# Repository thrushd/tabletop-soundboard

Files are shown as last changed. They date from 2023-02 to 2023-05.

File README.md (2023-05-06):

# Tabletop Soundboard
## In progress!
A simple, compact, easy to use device to add music, ambiance, and sound effects to any tabletop RPG.

## How To
All data is given to the device through a micro SD card. Audio files, the config, and gif are all placed in the root directory with no sub folders.

### Listening
There are two audio outputs on the device, USB audio and a standard 3.5mm jack. For the USB audio, you can easily loop it back to play through your computer speakers, a connected bluetooth speaker, etc. Instructions for setting up this loopback can be found [here](https://www.addictivetips.com/windows-tips/output-mic-sound-to-speakers-windows-10/) for windows. 

### Scenes and Settings
Sounds are organized into 'scenes', with each scene containing up to 8 tracks (sound files). This organization is set with a configuration file, written in [TOML](https://toml.io/en/). There are three main settings, which can be set at three different levels: global, scene, and track level. Priority for settings is always given to lower levels, so a track level setting will always override a scene level setting, etc. If a setting is not given to a scene or track it will use the next highest defined setting.

| Setting | Description |
| --- | --- |
| `gain` | The volume level, decimal values from `0-1` |
| `loop` | Whether a track should start playing again when it reaches the end, `true` or `false` |
| `play` | Whether a track should start playing immediately when a scene is activated, `true` or `false` |
| `name` | Override the name of the scene or track filename, used in scene and track definitions |
| `filename` | Filename of sound, used in track definitions, include the extension |
| `tracks` | A list of filenames used to create a scene with minimal input, same conventions as `filename` |

A scene is defined by making a name after the keyword `scenes`, enclosed in brackets. So to make a new scene called `tavern` you would write: `[scenes.tavern]`. Under this definition you can add your scene level settings. After that you can define tracks. This follows the same convention, just the scene name followed by a number representing which track it should be. So to define track 3 in scene `tavern` you would write: `[tavern.3]`. Same as the scene level definitions, under this you put all of your track level settings.

### Fixed Tracks
Sometimes you might have a sound that is used in every scene. So instead of copy-pasting the definition of the track into each scene, you can define it as a special `fixed` track with the notation `[fixed.N]`, with `N` being the track number. This does however mean you cannot have a scene named `fixed`.

### Startup Animation
Gifs are fun, so when the device is powered on it will play a gif on the main display if one is present on the SD card. This name can be changed in the config file under the table `[gifs]` with the setting `startup`. If this behaviour is not desired it can be left out of the config and the device will boot without it.

### Config Example
```TOML
# Default Settings, required
[default]
gain = 0.5
loop = false
play = false

# Startup animation filename
[gifs]
startup = "startup.gif"

# Create fixed tracks that don't change depending on which scene you are in
# If track.n is declared in a scene it is ignored and overriden with the below items
[fixed.7]
filename = "dj_airhorn.wav"
name = "Nat 20"
gain = 1.0
[fixed.8]
filename = "sad_trombone.wav"
name = "Nat 1"
gain = 1.0

# Create a scene
[scenes.tavern]
name = "Old Ivey Tavern"  # rename the scene if desired, otherwise it will show as 'tavern'
[tavern.1]  # add a track
filename = "tavern_sounds_1.wav"  # specify the filename
name = "Tavern Sounds"  # change the displayed name if you want
play = true  # set if it should play on scene start
loop = true  # set if the track should loop or not
gain = 0.3  # set a non default volume gain
[tavern.2]  # add another track
filename = "piano_3.wav"
name = "Piano"
play = true
gain = 0.75
[tavern.3]  # this track is fine with all of the default settings, no need to override
filename = "bang.wav"

[scenes.camp]
gain = 1.0
[camp.1]
filename = "wolf_howl.wav"
[camp.2]
filename = "wind.wav"
gain = 0.2
loop = true
play = true
[camp.3]
filename = "crackling_campfire.wav"
gain = 0.75
loop = true
play = true

# If defalt settings are fine it can get very minimal, just a list of the file names
[scenes.mountain]
loop = true
tracks = ["mountain_ambiance.wav", "avalanch.wav", "yetti_growl.wav"]
```

## Audio Files
### Format
The audio is handled by the teensy audio library, which only supports a certain format (16 bit PCM, 44100 Hz WAV files). Since most online resources provide all kinds of formats a simple tool is provided to convert these to the proper WAV format. It can be found under `/audio-convert`.

### Editing
[Audacity](https://www.audacityteam.org/) is a great free, open source, cross platform audio editor. It can be used to trim tracks you find online, add fade in/out, and other effects. 

[Getting started](https://manual.audacityteam.org/quick_help.html)

### Sources
- [Tabletop Audio](https://tabletopaudio.com/) - Good for longer, ambient tracks
- [Battlebards](https://battlebards.com/#/tracks) - Tons of variety, music, soundscapes, effects, voiceovers, but it is paid
- [Ambient Mixer RPG Category](https://rpg.ambient-mixer.com/) - Ambiance, user curated collections of tracks, no easy download, but there are sources given for most tracks
- [Freesound](https://freesound.org/) - Free, huge variety, need an account to download
- [SoundBible](https://soundbible.com/) - Free, decent collection, WAV format (need to right click and `save link as...` to actually download)
- [mixkit](https://mixkit.co/free-sound-effects/) - Free, decent collection, WAV format
- [pixabay](https://pixabay.com/sound-effects/) - Free, music and sound effects

## Feature Wishlist
- Scrolling text for longer file and scene names

## History
| Date | Firmware | PCBA | Case | 
| ---- | --- | ---- | ---- |
| 2022-02-19 | MVP working on breadboard | | |
| 2022-03-29 |  | First prototypes ordered | First prototypes ordered |
| 2023-04-22 | Ported to PCBA | Assembled and working | |

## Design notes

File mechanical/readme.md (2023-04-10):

Instructions on how to assemble the PCBA in the case. Tips for printing, sourcing, etc.

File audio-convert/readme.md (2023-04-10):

# Audio Conversion
Since the teensy requires a specific audio format (16 bit PCM, 44100 Hz WAV files), this simple GUI tool is provided as a convienience feature for batch converting audio files to the required format through FFMPEG.

## Instructions
1. Download, install, and verify FFPEG can be run from command line
2. Download and install python
3. Stage all files for conversion in a single folder
4. Double click the python script to run the GUI
5. Browse to the input directory, then browse to the directory you want the converted files to be in (this can be the same)
6. Convert!

If you just want to run the FFMPEG command without the GUI it's:
```
ffmpeg -i "example.mp3" -ar 44100 "example.wav"
```

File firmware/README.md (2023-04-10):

How to build PlatformIO based project (to be replaced)
=====================================

1. [Install PlatformIO Core](https://docs.platformio.org/page/core.html)
2. Download [development platform with examples](https://github.com/platformio/platform-teensy/archive/develop.zip)
3. Extract ZIP archive
4. Run these commands:

```shell
# Change directory to example
$ cd platform-teensy/examples/arduino-blink

# Build project
$ pio run

# Upload firmware
$ pio run --target upload

# Build specific environment
$ pio run -e teensy31

# Upload firmware for the specific environment
$ pio run -e teensy31 --target upload

# Clean build files
$ pio run --target clean
```

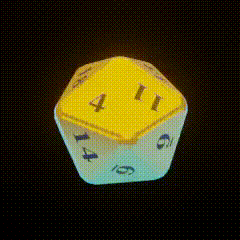
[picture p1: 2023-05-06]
sd/startup.gif

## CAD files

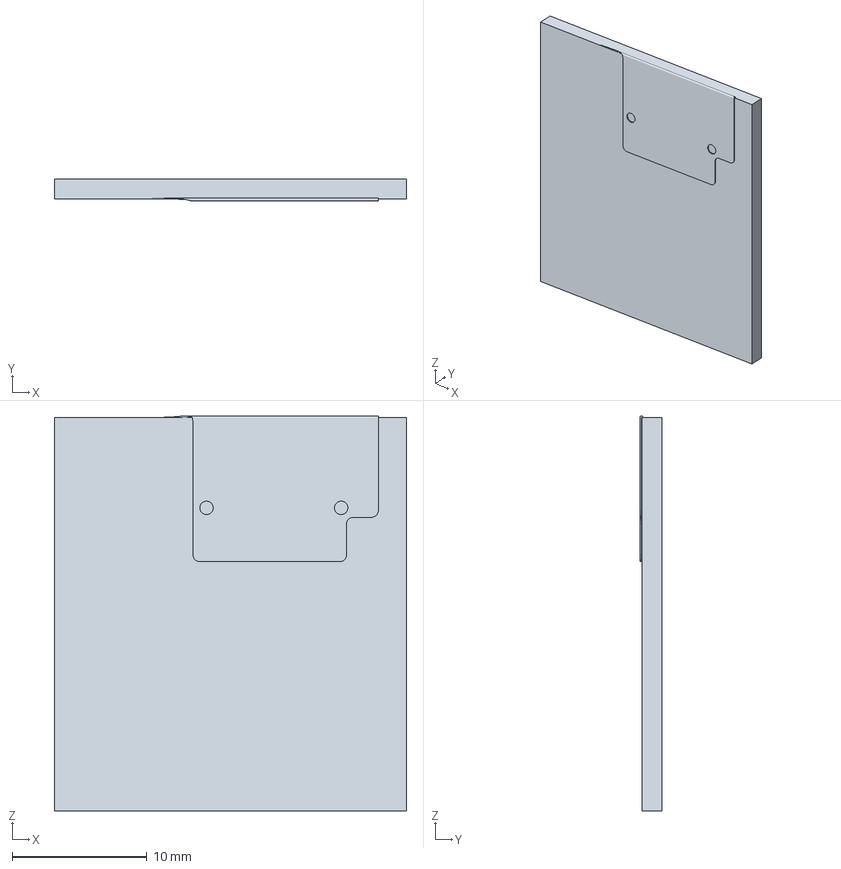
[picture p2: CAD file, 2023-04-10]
electrical/3d_models/ER-TFT013-2_tight.stp
26.2 x 1.64 x 29.3 mm

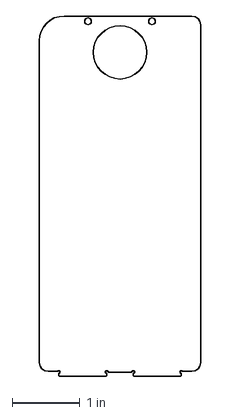
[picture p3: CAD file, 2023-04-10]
mechanical/plate.dxf
2.38 x 5.32 in

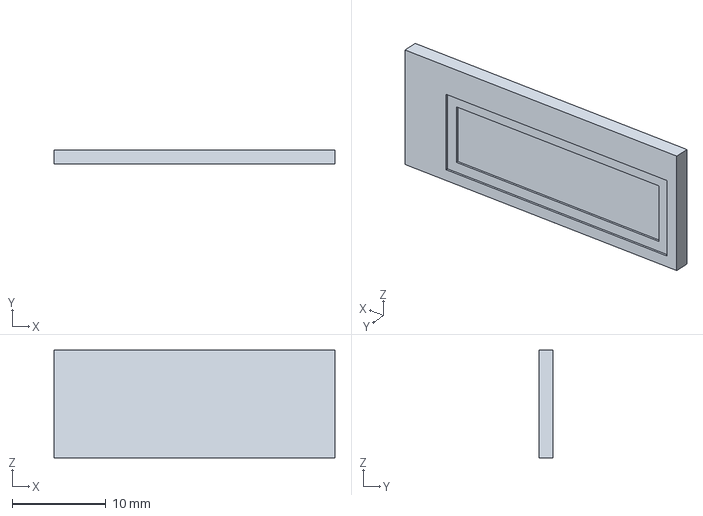
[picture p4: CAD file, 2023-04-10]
electrical/3d_models/ER-OLED0.91-1.stp
30.0 x 1.45 x 11.5 mm

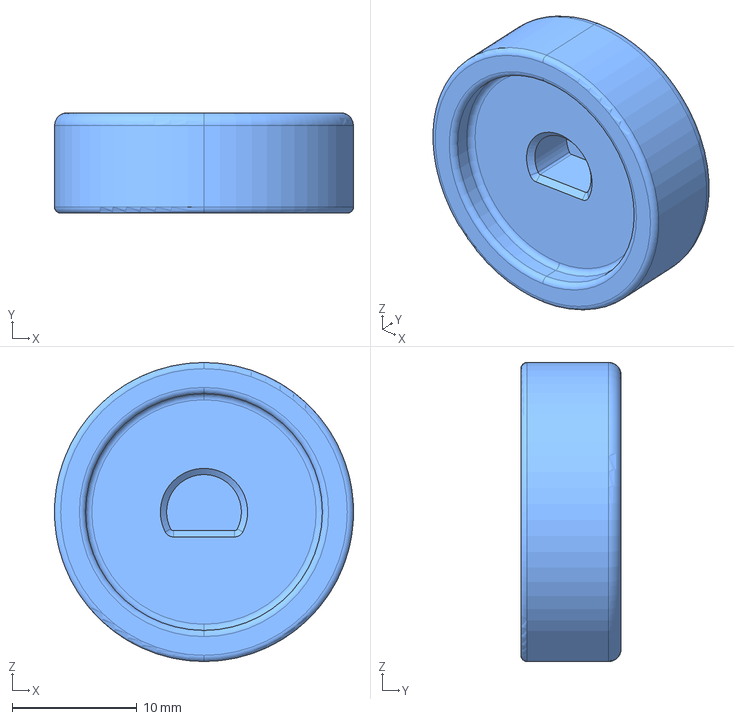
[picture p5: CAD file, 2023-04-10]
mechanical/knob.stp
24.0 x 8.05 x 24.0 mm

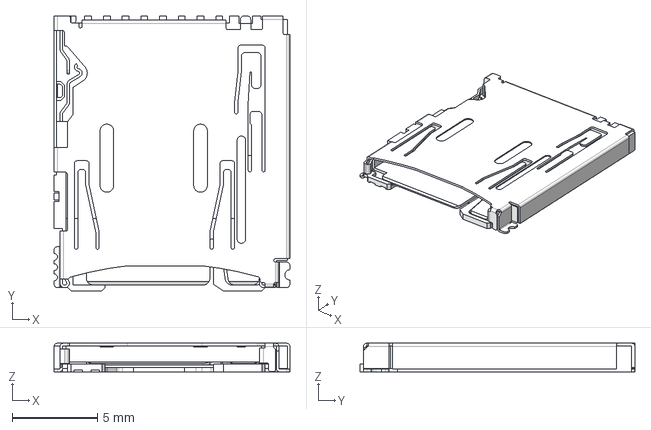
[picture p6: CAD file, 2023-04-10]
electrical/3d_models/DM3AT-SF-PEJM5.stp
13.8 x 16.2 x 1.68 mm

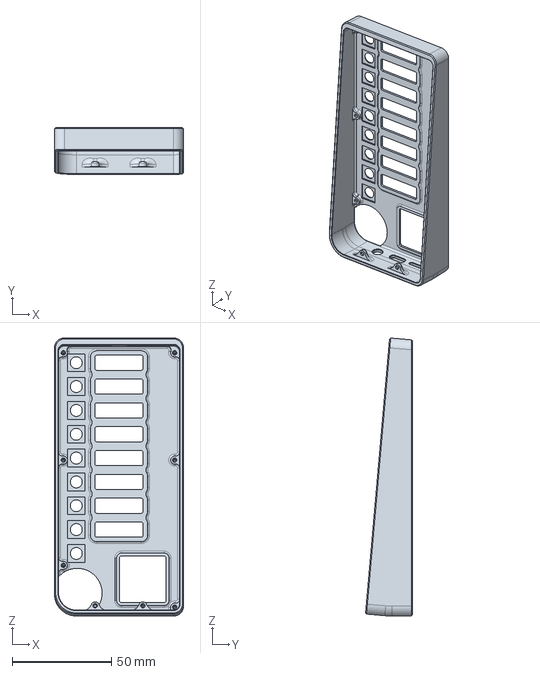
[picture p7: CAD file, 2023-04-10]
mechanical/case.stp
65.0 x 23.6 x 140.0 mm

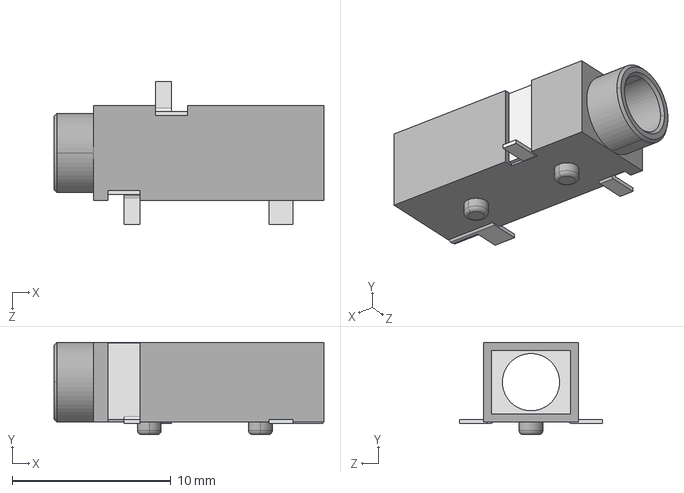
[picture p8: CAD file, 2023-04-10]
electrical/3d_models/CUI_DEVICES_SJ-3523-SMT-TR.step
17.0 x 5.80 x 9.00 mm

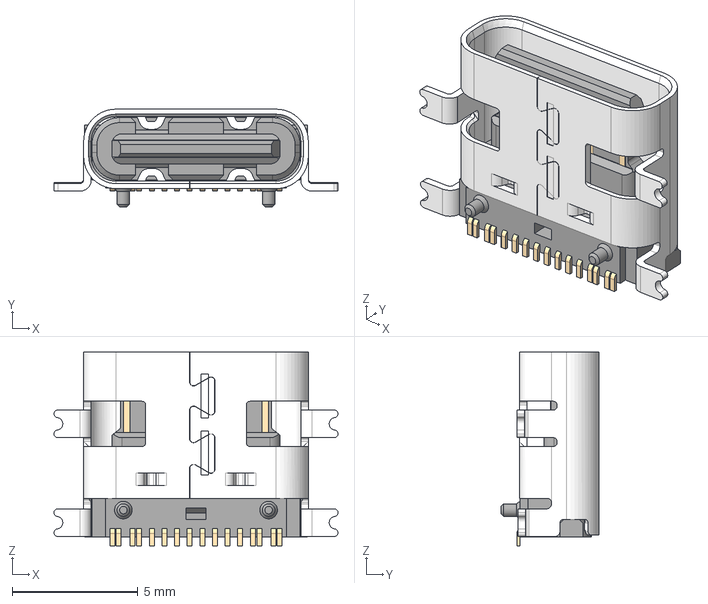
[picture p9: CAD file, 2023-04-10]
electrical/3d_models/USB4110-GF-A.stp
11.3 x 3.89 x 7.70 mm

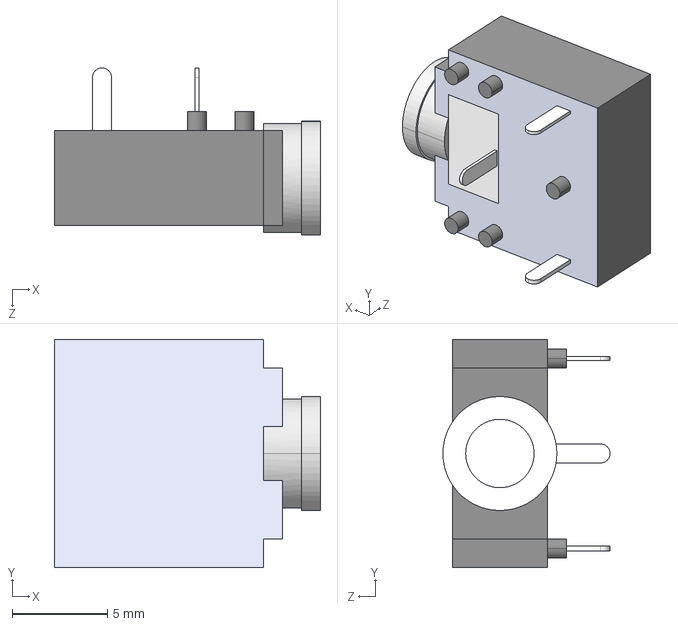
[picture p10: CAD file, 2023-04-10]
electrical/3d_models/CUI_DEVICES_SJ1-3523N.step
14.0 x 12.0 x 8.80 mm

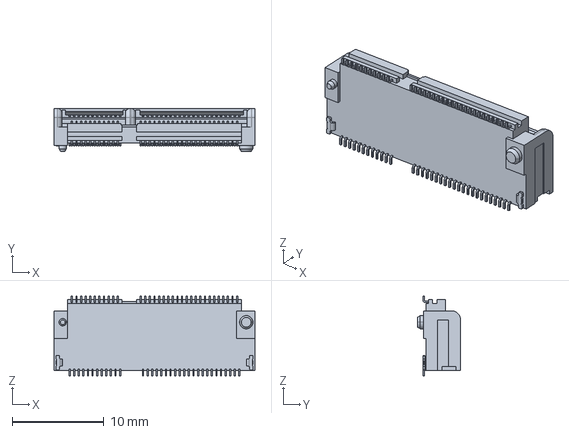
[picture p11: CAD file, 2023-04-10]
electrical/3d_models/c-2199230-4-b3-3d.stp
21.9 x 4.70 x 8.70 mm

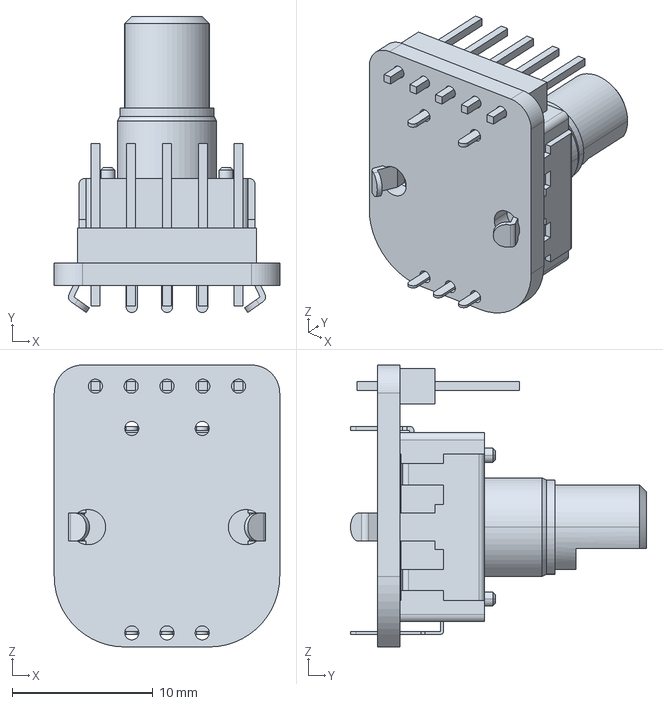
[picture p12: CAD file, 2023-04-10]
electrical/3d_models/encoder_undermount.stp
16.0 x 21.0 x 20.0 mm

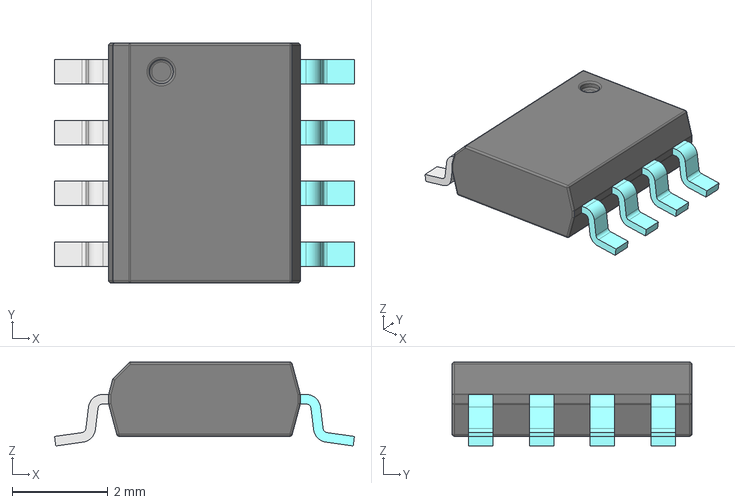
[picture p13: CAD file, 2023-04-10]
electrical/3d_models/SOIC8.stp
6.26 x 5.00 x 1.75 mm

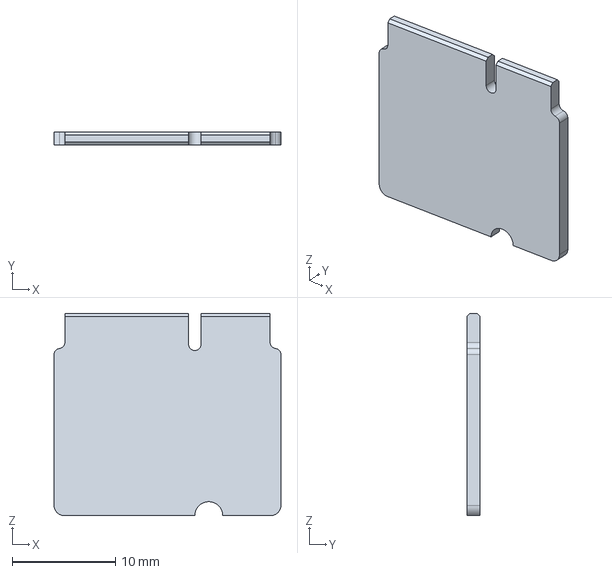
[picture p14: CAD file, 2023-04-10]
electrical/3d_models/micromod.stp
22.0 x 1.30 x 19.6 mm

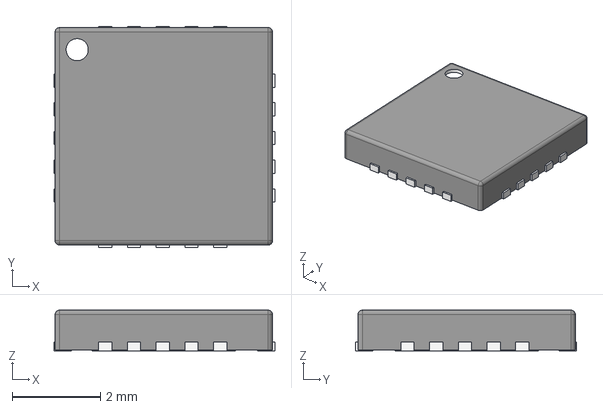
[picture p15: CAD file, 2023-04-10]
electrical/3d_models/QFN-20 (5x5x0.9).iges
5.00 x 5.00 x 0.92 mm

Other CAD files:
electrical/3d_models/TSSOP-24 0.65p.step
electrical/3d_models/ER-TFT013-2_loose.stp
electrical/3d_models/9774025151R (rev1).stp
electrical/3d_models/PEC12R-4215F-S0024.stp
mechanical/case.stl
mechanical/knob.stl

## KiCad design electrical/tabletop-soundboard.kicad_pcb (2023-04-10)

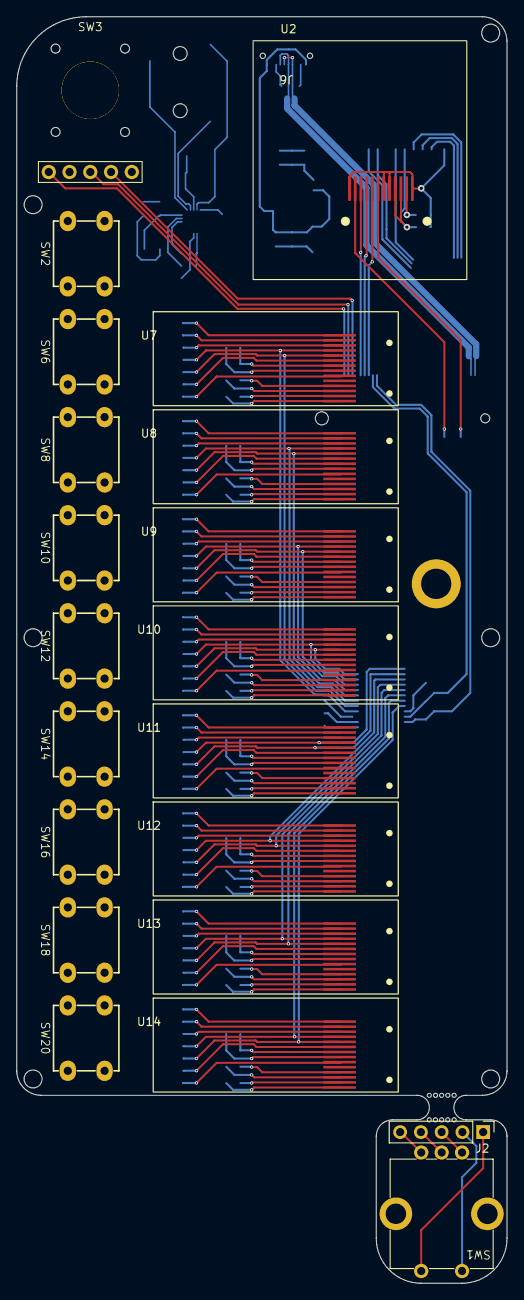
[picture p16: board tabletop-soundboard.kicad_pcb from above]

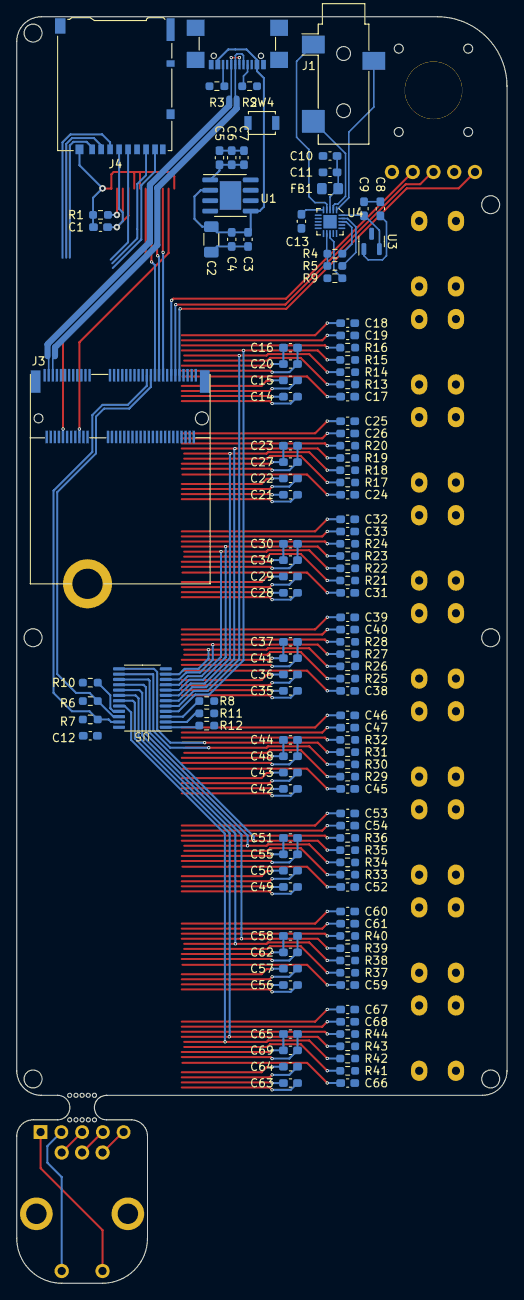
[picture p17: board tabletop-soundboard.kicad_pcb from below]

Board: 2 copper layers, 60.0 x 155.0 mm, 147 parts (125 on the bottom side), 145 nets.

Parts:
C1, C5, C8, C9: 1uF; C_0603_1608Metric_Pad1.08x0.95mm_HandSolder
C2: 10uF; C_1206_3216Metric_Pad1.33x1.80mm_HandSolder
C3, C6: 0.22uF; C_0603_1608Metric_Pad1.08x0.95mm_HandSolder
C4, C7, C11: 0.1uF; C_0603_1608Metric_Pad1.08x0.95mm_HandSolder
C10: 2.2uF; C_0603_1608Metric_Pad1.08x0.95mm_HandSolder
C12: 10uF; C_0603_1608Metric_Pad1.08x0.95mm_HandSolder
C13: 0.15uF; C_0603_1608Metric_Pad1.08x0.95mm_HandSolder
C14, C15, C16, C20, C21, C22, C23, C27, C28, C29, C30, C34, C35, C36, C37, C41, C42, C43, C44, C48, C49, C50, C51, C55, C56, C57, C58, C62, C63, C64, C65, C69: 1uf; C_0603_1608Metric_Pad1.08x0.95mm_HandSolder
C17, C24, C31, C38, C45, C52, C59, C66: 22nf; C_0603_1608Metric_Pad1.08x0.95mm_HandSolder
C18, C25, C32, C39, C46, C53, C60, C67: 2.2uf; C_0603_1608Metric_Pad1.08x0.95mm_HandSolder
C19, C26, C33, C40, C47, C54, C61, C68: 4.7uf; C_0603_1608Metric_Pad1.08x0.95mm_HandSolder
FB1: Ferrite 600; R_0805_2012Metric_Pad1.20x1.40mm_HandSolder
J1: AudioJack3; Jack_3.5mm_CUI_SJ-3523-SMT_Horizontal
J2: HEADER; PinHeader_1x05_P2.54mm_Vertical
J3: micromod_teensy; M.2_connector_TE-2199230-4
J4: Micro_SD_Card_Det2; microSD_HC_Hirose_DM3AT-SF-PEJM5
J5: standoff_9774025151R
J6: USB_C_Receptacle; USB_C_Receptacle_GCT_USB4110
R1: 10; R_0603_1608Metric_Pad0.98x0.95mm_HandSolder
R2, R3: 5.1k; R_0603_1608Metric_Pad0.98x0.95mm_HandSolder
R4, R5: 2.2k; R_0603_1608Metric_Pad0.98x0.95mm_HandSolder
R6, R7, R8, R10, R11, R12: 10k; R_0603_1608Metric_Pad0.98x0.95mm_HandSolder
R9: 100; R_0603_1608Metric_Pad0.98x0.95mm_HandSolder
R13, R14, R15, R17, R18, R19, R21, R22, R23, R25, R26, R27, R29, R30, R31, R33, R34, R35, R37, R38, R39, R41, R42, R43: 4.7k; R_0603_1608Metric_Pad0.98x0.95mm_HandSolder
R16, R20, R24, R28, R32, R36, R40, R44: 390K; R_0603_1608Metric_Pad0.98x0.95mm_HandSolder
SW1: ENCODER; encoder_PEC12R-4215F-S0024
SW2: STOP ALL; BUTTON_SOFT_TACTILE
SW3: UNDER MOUNTED ENCODER; encoder_PEC12R-4XXXF-SXXX_undermount
SW4: PROG; SW_SPST_B3U-1000P
SW6, SW8, SW10, SW12, SW14, SW16, SW18, SW20: TRIGGER; BUTTON_SOFT_TACTILE
U1: AP7361C-33SP; SOIC-8
U2: ER-TFT013-2
U3: AP7313-12SRG-7; SOT-23
U4: SGTL5000XNLA3; QFN-20-1EP_3x3mm_P0.4mm_EP1.65x1.65mm
U5: TCA9548APWR; TSSOP-24-0.65mm
U6: MICROMOD
U7, U8, U9, U10, U11, U12, U13, U14: ER-OLED0.91-7W; ER-OLED0.91-1
mouse-bite-3mm-slot: mouse-bite-3mm-slot

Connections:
+3.3V: C1.1, C5.1, C6.1, C7.1, C8.1, C12.1, C16.1, C20.2, C23.1, C27.2, C30.1, C34.2, C37.1, C41.2, C44.1, C48.2, C51.1, C55.2, C58.1, C62.2, C65.1, C69.2, FB1.1, J3.2 (3.3V), J3.74 (3.3V), J4.4 (VDD), R4.2, R5.2, R6.2, R7.2, R8.2, R13.1, R14.1, R15.1, R17.1, R18.1, R19.1, R21.1, R22.1, R23.1, R25.1, R26.1, R27.1, R29.1, R30.1, R31.1, R33.1, R34.1, R35.1, R37.1, R38.1, R39.1, R41.1, R42.1, R43.1, U1.1 (OUT), U2.3 (LEDA), U2.4 (VDD), U3.1 (IN), U4.12 (VDDIO), U5.24 (VCC), U7.5 (VBAT), U7.8 (VDD), U8.5 (VBAT), U8.8 (VDD), U9.5 (VBAT), U9.8 (VDD), U10.5 (VBAT), U10.8 (VDD), U11.5 (VBAT), U11.8 (VDD), U12.5 (VBAT), U12.8 (VDD), U13.5 (VBAT), U13.8 (VDD), U14.5 (VBAT), U14.8 (VDD)
/module1/SCL: R18.2, U5.7 (SC1), U8.10 (SCL)
/module1/SDA: R19.2, U5.6 (SD1), U8.11 (SDA)
/module2/SCL: R22.2, U5.9 (SC2), U9.10 (SCL)
/module2/SDA: R23.2, U5.8 (SD2), U9.11 (SDA)
/module3/SCL: R26.2, U5.11 (SC3), U10.10 (SCL)
/module3/SDA: R27.2, U5.10 (SD3), U10.11 (SDA)
/module4/SCL: R30.2, U5.14 (SC4), U11.10 (SCL)
/module4/SDA: R31.2, U5.13 (SD4), U11.11 (SDA)
/module5/SCL: R34.2, U5.16 (SC5), U12.10 (SCL)
/module5/SDA: R35.2, U5.15 (SD5), U12.11 (SDA)
/module6/SCL: R38.2, U5.18 (SC6), U13.10 (SCL)
/module6/SDA: R39.2, U5.17 (SD6), U13.11 (SDA)
/module7/SCL: R42.2, U5.20 (SC7), U14.10 (SCL)
/module7/SDA: R43.2, U5.19 (SD7), U14.11 (SDA)
/module/SCL: R14.2, U5.5 (SC0), U7.10 (SCL)
/module/SDA: R15.2, U5.4 (SD0), U7.11 (SDA)
AUD_BCLK: J3.50 (AUD_BCLK/21), U4.15 (I2S_SCLK)
AUD_IN: J3.54 (AUD_IN/8), U4.16 (I2S_DOUT)
AUD_LRCLK: J3.52 (AUD_LRCLK/20), U4.14 (I2S_LRCLK)
AUD_MCLK: J3.58 (AUD_MCLK/23), R9.1
AUD_OUT: J3.56 (AUD_OUT/7), U4.17 (I2S_DIN)
D0: J3.10 (D0/4), U2.7 (D/C)
D1: J3.18 (D1/5), U2.11 (RESET)
G0: J3.40 (G0/40), SW6.1, SW6.2
G1: J3.42 (G1/41), SW8.1, SW8.2
G2: J3.44 (G2/42), SW10.1, SW10.2
G3: J3.46 (G3/43), SW12.1, SW12.2
G4: J3.48 (G4/44), SW14.1, SW14.2
G5: J3.73 (G5/45), SW16.1, SW16.2
G6: J3.71 (G6/6), SW18.1, SW18.2
G7: J3.69 (G7/9), SW20.1, SW20.2
G8: J3.67 (G8/26), SW3.1 (S1)
G9: J3.65 (G9/32), SW3.A
G10: J3.63 (G10/33), SW3.B
G11: J3.8 (G11/27), SW2.1, SW2.2
GND: C1.2, C2.2, C3.2, C4.2, C5.2, C6.2, C7.2, C8.2, C9.2, C10.2, C11.2, C12.2, C13.2, C16.2, C17.2, C18.2, C19.2, C20.1, C23.2, C24.2, C25.2, C26.2, C27.1, C30.2, C31.2, C32.2, C33.2, C34.1, C37.2, C38.2, C39.2, C40.2, C41.1, C44.2, C45.2, C46.2, C47.2, C48.1, C51.2, C52.2, C53.2, C54.2, C55.1, C58.2, C59.2, C60.2, C61.2, C62.1, C65.2, C66.2, C67.2, C68.2, C69.1, J3.1 (GND), J3.7 (GND), J3.33 (GND), J3.36 (GND), J3.39 (GND), J3.45 (GND), J3.75 (GND), J4.6 (VSS), J4.11 (SHIELD), J5.1, J6.A1 (GND), J6.A12 (GND), J6.B1 (GND), J6.B12 (GND), R1.1, R2.2, R3.2, R10.1, R11.1, R12.1, R16.2, R20.2, R24.2, R28.2, R32.2, R36.2, R40.2, R44.2, SW2.3, SW2.4, SW3.2 (S2), SW3.C, SW4.1, SW6.3, SW6.4, SW8.3, SW8.4, SW10.3, SW10.4, SW12.3, SW12.4, SW14.3, SW14.4, SW16.3, SW16.4, SW18.3, SW18.4, SW20.3, SW20.4, U1.4 (GND), U2.1 (GND), U2.5 (GND), U2.6 (GND), U2.12 (GND), U3.3 (GND), U4.21 (GND), U5.12 (GND), U7.7 (VSS), U8.7 (VSS), U9.7 (VSS), U10.7 (VSS), U11.7 (VSS), U12.7 (VSS), U13.7 (VSS), U14.7 (VSS)
I2C_SCL: J3.14 (I2C_SCL/19), R5.1, U4.19 (CTRL_CLK)
I2C_SCL_1: J3.53 (I2C_SCL1/24), R6.1, U5.22 (SCL)
I2C_SDA: J3.12 (I2C_SDA/18), R4.1, U4.18 (CTRL_DATA)
I2C_SDA_1: J3.51 (I2C_SDA1/25), R7.1, U5.23 (SDA)
unnamed: J2.1, SW1.2 (S2)
unnamed: J2.2, SW1.1 (S1)
unnamed: J2.3, SW1.A
unnamed: J2.4, SW1.C
unnamed: J2.5, SW1.B
unnamed: J3.11 (BOOT/PROG), SW4.2
unnamed: J3.62 (SDIO_CMD/37), J4.3 (CMD)
unnamed: J3.64 (SDIO_DATA0/35), J4.7 (DAT0)
unnamed: J3.66 (SDIO_DATA1/34), J4.8 (DAT1)
unnamed: J3.68 (SDIO_DATA2/39), J4.1 (DAT2)
unnamed: J3.70 (SDIO_DATA3/38), J4.2 (DAT3/CD)
unnamed: J3.60 (SDIO_SCK/36), J4.5 (CLK)
unnamed: J6.A5 (CC1), R2.1
unnamed: J6.B5 (CC2), R3.1
unnamed: R1.2, U2.2 (LEDK)
unnamed: C9.1, U3.2 (OUT), U4.20 (VDDD)
unnamed: J1.S, U4.4 (HP_L)
unnamed: J1.R, U4.1 (HP_R)
unnamed: J1.T, U4.2 (HP_VGND)
unnamed: R9.2, U4.13 (SYS_MCLK)
unnamed: C13.1, U4.5 (VAG)
unnamed: C10.1, C11.1, FB1.2, U4.3 (VDDA)
unnamed: R12.2, U5.1 (A0)
unnamed: R11.2, U5.2 (A1)
unnamed: R10.2, U5.21 (A2)
unnamed: R8.1, U5.3 (~RESET)
unnamed: C15.2, U7.4 (C1N)
unnamed: C15.1, U7.3 (C1P)
unnamed: C14.2, U7.2 (C2N)
unnamed: C14.1, U7.1 (C2P)
unnamed: R16.1, U7.12 (IREF)
unnamed: R13.2, U7.9 (RES)
unnamed: C17.1, U7.6 (VBREF)
unnamed: C18.1, U7.14 (VCC)
unnamed: C19.1, U7.13 (VCOMH)
unnamed: C22.2, U8.4 (C1N)
unnamed: C22.1, U8.3 (C1P)
unnamed: C21.2, U8.2 (C2N)
unnamed: C21.1, U8.1 (C2P)
unnamed: R20.1, U8.12 (IREF)
unnamed: R17.2, U8.9 (RES)
unnamed: C24.1, U8.6 (VBREF)
unnamed: C25.1, U8.14 (VCC)
unnamed: C26.1, U8.13 (VCOMH)
unnamed: C29.2, U9.4 (C1N)
unnamed: C29.1, U9.3 (C1P)
unnamed: C28.2, U9.2 (C2N)
unnamed: C28.1, U9.1 (C2P)
unnamed: R24.1, U9.12 (IREF)
unnamed: R21.2, U9.9 (RES)
unnamed: C31.1, U9.6 (VBREF)
unnamed: C32.1, U9.14 (VCC)
unnamed: C33.1, U9.13 (VCOMH)
unnamed: C36.2, U10.4 (C1N)
unnamed: C36.1, U10.3 (C1P)
unnamed: C35.2, U10.2 (C2N)
unnamed: C35.1, U10.1 (C2P)
unnamed: R28.1, U10.12 (IREF)
unnamed: R25.2, U10.9 (RES)
unnamed: C38.1, U10.6 (VBREF)
unnamed: C39.1, U10.14 (VCC)
unnamed: C40.1, U10.13 (VCOMH)
unnamed: C43.2, U11.4 (C1N)
unnamed: C43.1, U11.3 (C1P)
unnamed: C42.2, U11.2 (C2N)
unnamed: C42.1, U11.1 (C2P)
unnamed: R32.1, U11.12 (IREF)
unnamed: R29.2, U11.9 (RES)
unnamed: C45.1, U11.6 (VBREF)
unnamed: C46.1, U11.14 (VCC)
unnamed: C47.1, U11.13 (VCOMH)
unnamed: C50.2, U12.4 (C1N)
unnamed: C50.1, U12.3 (C1P)
unnamed: C49.2, U12.2 (C2N)
unnamed: C49.1, U12.1 (C2P)
unnamed: R36.1, U12.12 (IREF)
unnamed: R33.2, U12.9 (RES)
unnamed: C52.1, U12.6 (VBREF)
unnamed: C53.1, U12.14 (VCC)
unnamed: C54.1, U12.13 (VCOMH)
unnamed: C57.2, U13.4 (C1N)
unnamed: C57.1, U13.3 (C1P)
unnamed: C56.2, U13.2 (C2N)
unnamed: C56.1, U13.1 (C2P)
unnamed: R40.1, U13.12 (IREF)
unnamed: R37.2, U13.9 (RES)
unnamed: C59.1, U13.6 (VBREF)
unnamed: C60.1, U13.14 (VCC)
unnamed: C61.1, U13.13 (VCOMH)
unnamed: C64.2, U14.4 (C1N)
unnamed: C64.1, U14.3 (C1P)
unnamed: C63.2, U14.2 (C2N)
unnamed: C63.1, U14.1 (C2P)
unnamed: R44.1, U14.12 (IREF)
unnamed: R41.2, U14.9 (RES)
unnamed: C66.1, U14.6 (VBREF)
unnamed: C67.1, U14.14 (VCC)
unnamed: C68.1, U14.13 (VCOMH)
SPI_CLK: J3.57 (SPI_SCK/13), U2.9 (SCL)
SPI_COPI: J3.59 (SPI_COPI/11), U2.10 (SDA)
SPI_CS: J3.55 (SPI_CS/10), U2.8 (CS)
USB_N: J3.5 (USB_D-), J6.A7 (D-), J6.B7 (D-)
USB_P: J3.3 (USB_D+), J6.A6 (D+), J6.B6 (D+)
VCC: C2.1, C3.1, C4.1, J3.9 (USB_VIN/V_USB), J6.A4 (VBUS), J6.A9 (VBUS), J6.B4 (VBUS), J6.B9 (VBUS), U1.2 (EN), U1.5 (IN)

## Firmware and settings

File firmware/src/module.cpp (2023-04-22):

#include "module.h"

Module::Module(int module_number, int button_pin, AudioPlaySdWav* play_sd, AudioMixer4* mixer_left, AudioMixer4* mixer_right, TwoWire* twi, Encoder* knob)
{
    this->module_number = module_number;
    this->button_pin = button_pin;
    this->play_sd = play_sd;
    this->mixer_left = mixer_left;
    this->mixer_right = mixer_right;
    this->twi = twi;
    this->knob = knob;
}

void Module::init(Track** tracks_in)
{
    this->tracks = tracks_in;
    // init button
    button = OneButton(button_pin, true, true);
    button.attachClick(handle_single, this);
    // button.attachDoubleClick(handle_double, this);
    button.attachDuringLongPress(handle_hold, this);

    // init display
    set_mp_addr();
    display = Adafruit_SSD1306(MODULE_SCREEN_WIDTH, MODULE_SCREEN_HEIGHT, twi, OLED_RESET);
    display.begin(SSD1306_SWITCHCAPVCC, SCREEN_ADDRESS);
    display.clearDisplay(); // clear the buffer

    // display.setCursor(0, 0);
    // display.setTextSize(2);
    // display.setTextColor(SSD1306_WHITE);
    // display.print("Started!");

    display.display(); // display the empty screen
}

void Module::update(int new_scene_index)
{
    // Serial.printf("in module %d\n", module_number);
    // a scene has not been selected yet
    if (new_scene_index < 0) {
        // Serial.println("1");
        return;
    }

    // new scene checks
    if (new_scene_index != scene_index) {
        // Serial.println("2");
        scene_index = new_scene_index;
        skip = false;
        play_flag = false;
        loop_flag = false;

        // check if the filename is actually populated, min 5 characters for a valid file
        if (strlen(tracks[scene_index][module_number].filename) < 5) {
            // Serial.println("3");
            skip = true;
            display_empty();
            return;
        }
        // check if the filename is actually on the SD card
        if (!SD.exists(tracks[scene_index][module_number].filename)) {
            // Serial.println("4");
            skip = true;
            display_file_not_found();
            return;
        }
        // Serial.println("5");

        // update the track duration
        // need to play briefly since lengthMillis only returns while playing
        Serial.println("1");
        play_sd->play(tracks[scene_index][module_number].filename);
        // TODO, this seems hacky and might be bad downstream
        Serial.println("2");
        while (!play_sd->isPlaying()) {} // block until the wav header is parsed, otherwise lengthMillis returns nothing
        Serial.println("3");
        track_duration = play_sd->lengthMillis();
        Serial.println("4");
        play_sd->stop();

        // track_duration = 1000000;

        // TODO the loop flag causes tracks to start playing immediately, even when play is set to false

        // Serial.println("6");
        // set flags
        if (tracks[scene_index][module_number].play) {
            play_flag = true;
        }
        // // set the play flag if we should be looping
        // if (tracks[scene_index][module_number].loop) {
        //     loop_flag = true;
        // }
        return;
    }

    // previously we determined that the filename given was trash, so just skip
    if (skip) {
        return;
    }

    // second time through the loop, start playing
    if (play_flag) {
        play_flag = false;
        play_sd->play(tracks[scene_index][module_number].filename);
    }

    // update buttons
    button.tick();

    // restart if the track finished and we want to loop
    if (tracks[scene_index][module_number].loop) {
        if (loop_flag && play_sd->isStopped()) {
            play_sd->play(tracks[scene_index][module_number].filename);
        }
    }

    // update gains
    // read new position
    long new_position = knob->read();
    // if it's changed
    if (new_position != old_position) {
        // get the difference as an integer
        long diff_int = old_position - new_position;
        // reset old position
        old_position = new_position;
        // map the difference into the range of gain
        gain_diff = double(map_float(diff_int, enc_int_min, enc_int_max, GAIN_MIN, GAIN_MAX));
    }

    mixer_left->gain(module_number % 4, tracks[scene_index][module_number].gain);
    mixer_right->gain(module_number % 4, tracks[scene_index][module_number].gain);

    update_display();
}

// set the multiplexer address to the current module
void Module::set_mp_addr()
{
    twi->beginTransmission(TCA_ADDR);
    twi->write(1 << module_number);
    twi->endTransmission();
}

// main display update function
void Module::update_display()
{
    set_mp_addr();
    display.clearDisplay(); // clear the buffer
    // track name, centered
    // rescale text size if name is too long to fit as size 2, can currently fit 10 chars before newline with size 2, 21 chars on a single line with size 1, will wrap if over that for a max total of 42
    if (strlen(tracks[scene_index][module_number].name) > 10) {
        display.setTextSize(1);
    } else {
        display.setTextSize(2);
    }
    display.setTextColor(SSD1306_WHITE);
    int16_t text_x, text_y;
    uint16_t text_w, text_h;
    display.getTextBounds(tracks[scene_index][module_number].name, 0, 0, &text_x, &text_y, &text_w, &text_h);
    display.setCursor((MODULE_SCREEN_WIDTH - text_w) / 2, (MODULE_SCREEN_HEIGHT / 2 - text_h) / 2);
    display.print(tracks[scene_index][module_number].name);

    // track length, count down when playing
    display.setTextSize(1);
    display.setCursor(6, 24);
    display.print(millis_to_hhmmss(track_duration - play_sd->positionMillis()));

    // draw track progress
    rect_progress_bar(54, 24, 74, 8, play_sd->positionMillis(), track_duration);

    // draw gain bar
    volume_display(26, 16, 72, 6, tracks[scene_index][module_number].gain, GAIN_MAX);

    // gain number
    display.setCursor(104, 16);
    display.printf("G%0.1f", tracks[scene_index][module_number].gain);

    // loop
    display.drawChar(6, 16, 0x4C, SSD1306_WHITE, SSD1306_BLACK, 1); // draw L
    if (tracks[scene_index][module_number].loop) {
        display.drawChar(0, 16, 0x2B, SSD1306_WHITE, SSD1306_BLACK, 1); // draw + if yes
    } else {
        display.drawChar(0, 16, 0x2D, SSD1306_WHITE, SSD1306_BLACK, 1); // draw - if no
    }

    // play
    display.drawChar(18, 16, 0x50, SSD1306_WHITE, SSD1306_BLACK, 1); // draw P
    if (tracks[scene_index][module_number].play) {
        display.drawChar(12, 16, 0x2B, SSD1306_WHITE, SSD1306_BLACK, 1); // draw + if yes
    } else {
        display.drawChar(12, 16, 0x2D, SSD1306_WHITE, SSD1306_BLACK, 1); // draw - if no
    }
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

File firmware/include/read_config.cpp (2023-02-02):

#include "read_config.h"
#include "helper_functions.h"


// TODO: hangs if you specify track numbers over this limit
const int n_modules = 8;

// return the number of keys in a table
int size_of_toml_table(toml_table_t* table)
{
    for (int i = 0;; i++) {
        const char* key = toml_key_in(table, i);
        if (!key) {
            return i;
        }
    }
    return 0;
}

// print out track for debugging
void print_track(Track input_track)
{
    Serial.print("Filename: ");
    Serial.println(input_track.filename);
    Serial.print("Name: ");
    Serial.println(input_track.name);
    Serial.print("Gain: ");
    Serial.println(input_track.gain);
    Serial.print("Loop: ");
    Serial.println(input_track.loop);
    Serial.print("Play: ");
    Serial.println(input_track.play);
    Serial.println();
}

// extract all track data to a track object from a given toml track table, using defaults if no settings present
Track table_to_track(toml_table_t* input_table, double default_gain, bool default_loop, bool default_play)
{
    Track track;
    // read in filename, this is the only required attribute, so hard fail if it's not here
    toml_datum_t fixed_track_filename = toml_string_in(input_table, "filename");
    if (!fixed_track_filename.ok) {
        fatal("Cannot find fixed track filename", "");
    }
    memcpy(track.filename, fixed_track_filename.u.s, MAX_CHAR);

    // read in name, use filename if not given
    toml_datum_t fixed_track_name = toml_string_in(input_table, "name");
    if (!fixed_track_name.ok) {
        // TODO: find a way to trim off the file extension for the name
        memcpy(track.name, fixed_track_filename.u.s, MAX_CHAR);
    } else {
        memcpy(track.name, fixed_track_name.u.s, MAX_CHAR);
        free(fixed_track_name.u.s);
    }
    free(fixed_track_filename.u.s);

    // read in gain, use default if not given
    toml_datum_t fixed_track_gain = toml_double_in(input_table, "gain");
    if (!fixed_track_gain.ok) {
        track.gain = default_gain;
    } else {
        track.gain = fixed_track_gain.u.d;
    }

    // read in loop, use default if not given
    toml_datum_t fixed_track_loop = toml_bool_in(input_table, "loop");
    if (!fixed_track_loop.ok) {
        track.loop = default_loop;
    } else {
        track.loop = fixed_track_loop.u.b;
    }

    // read in play, use default if not given
    toml_datum_t fixed_track_play = toml_bool_in(input_table, "play");
    if (!fixed_track_play.ok) {
        track.play = default_play;
    } else {
        track.play = fixed_track_play.u.b;
    }
    return track;
}

// load all settings from the config file
void load_config()
{
    // first check if the file even exists
    if (SD.exists(config_file_name)) {
        Serial.print("config found, ");
    } else {
        fatal("config not found", "");
    }

    // create file to hold contents
    File config_file;

    // read toml file
    config_file = SD.open(config_file_name, FILE_READ);
    if (!config_file) {
        fatal("cannot open config ", "");
    }
    Serial.print("opened, ");

    // read file into a char buffer so it can be fed into the parser
    // A bit hacky right now, if a user inputs a massive config file this might cause issues
    // TODO: Make toml read buffer less hacky, maybe using malloc?
    int config_size = config_file.size();
    char tomlbuffer[config_size];
    char errbuf[200];
    int index = 0;
    while (config_file.available()) {
        char c = config_file.read();
        tomlbuffer[index] = c;
        if (c == 0)
            break; // end of string
        index = index + 1;
        if (index == config_size)
            break; // buffer full
    }
    tomlbuffer[index] = 0;
    // print out the raw file for debugging
    // Serial.println("raw file contents: ");
    // Serial.println("");
    // Serial.println(tomlbuffer);

    // parse the file
    toml_table_t* conf = toml_parse(tomlbuffer, errbuf, sizeof(errbuf));
    Serial.print("read, ");
    config_file.close();
    Serial.print("closed, ");

    if (!conf) {
        fatal("cannot parse - ", errbuf);
    }
    Serial.println("parsed.");

    // find the default table, can't proceed without it
    toml_table_t* default_table = toml_table_in(conf, "default");
    if (!default_table)
        fatal("missing default settings", "");

    // extract default values, hard quit if none are present
    toml_datum_t default_loop_datum = toml_bool_in(default_table, "loop");
    if (!default_loop_datum.ok)
        fatal("missing default loop", "");
    bool default_loop = default_loop_datum.u.b;

    toml_datum_t default_play_datum = toml_bool_in(default_table, "play");
    if (!default_play_datum.ok)
        fatal("missing default play", "");
    bool default_play = default_play_datum.u.b;

    toml_datum_t default_gain_datum = toml_double_in(default_table, "gain");
    if (!default_gain_datum.ok)
        fatal("missing default gain", "");
    double default_gain = default_gain_datum.u.d;

    // extract the gif name
    toml_table_t* gif_table = toml_table_in(conf, "gifs");
    if (gif_table){
        toml_datum_t startup_gif_toml = toml_string_in(gif_table, "startup");
        if (startup_gif_toml.ok){
            memcpy(gif_name, startup_gif_toml.u.s, MAX_CHAR);
            free(startup_gif_toml.u.s);
        }
    }

    // traverse and extract any fixed tracks
    // arrays need to be outside and fixed size because dumb
    Track fixed_tracks[n_modules];
    toml_table_t* fixed_table = toml_table_in(conf, "fixed");
    if (fixed_table) {
        // fixed tracks present, get em
        int n_fixed_tracks = size_of_toml_table(fixed_table);
        Serial.print("found ");
        Serial.print(n_fixed_tracks);
        Serial.println(" fixed tracks");

        // populate array
        for (int i = 0; ; i++) {
            const char* key = toml_key_in(fixed_table, i);
            if (!key){
                break;
            }
            // error check the track number that was entered
            if (atoi(key) > n_modules){
                fatal("fixed track number exeeds number of modules", "");
            }
            // extract table and get track
            toml_table_t* fixed_subtable = toml_table_in(fixed_table, key);
            fixed_tracks[atoi(key) - 1] = table_to_track(fixed_subtable, default_gain, default_loop, default_play);
        }
    } else {
        Serial.println("no fixed tracks found");
    }

    // find the scene table
    toml_table_t* scenes_table = toml_table_in(conf, "scenes");
    if (!scenes_table) {
        fatal("no scenes found", "");
    }

    // yo how many scenes we got
    int n_scenes = size_of_toml_table(scenes_table);
    
    // assign the external variable for use outside the function
    *n_scenes_ptr = n_scenes;
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

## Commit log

2022-12-25 broke read_config functions into their own files
    [read_config.cpp]
2022-12-27 Basic prototype of main screen scene selection
2023-01-16 Added soundboard class and am working on reworking read_config. Also added a gif display class that is not working
    [display_gif.cpp, module.h, read_config.cpp]
2023-01-18 Read config is almost working, just doesn't seem to actually be modifying the values outside the functions
    [read_config.cpp]
2023-02-15 Things are mostly all working together, with only a couple more bugs
    [module.cpp, module.h]
2023-04-10 Added electrical and mechanical first revisions
    [222KJVAAR.stp, 9774025151R (rev1).stp, CUI_DEVICES_SJ-3523-SMT-TR.step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]
2023-04-22 Started to port firmware to micromod / PCB layout

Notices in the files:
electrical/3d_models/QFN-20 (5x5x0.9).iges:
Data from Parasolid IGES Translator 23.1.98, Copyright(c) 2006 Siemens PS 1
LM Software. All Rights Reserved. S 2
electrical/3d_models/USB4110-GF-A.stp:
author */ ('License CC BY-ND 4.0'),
